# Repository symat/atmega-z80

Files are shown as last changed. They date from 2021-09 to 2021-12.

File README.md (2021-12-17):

ATMega-Z80
==========

We are building here yet another 8bit hobby computer. Because it is fun. And this is what an engineer does, *"MIDWAY upon the journey of our life"*. ;)

Disclaimer: **Use anything in this repo with caution!**

Nothing works yet, we just started to plan the whole thing. The only thing we are sure is that things will change, as we move forward. Plus the fact that we will move forward very slooowly, as this is only a hobby project and everyone is quite busy with other things. 

Table of Contents
-----------------

  * [Goals](#goals)
  * [Hardware design](#hardware-design)
    * [Schema](#schema)
    * [PCB](#pcb)
  * [Using the board](#using-the-board)
  * [Development](#development)
    * [Prerequisites for Linux](#prerequisites-for-linux)
    * [Prerequisites for Windows](#prerequisites-for-windows)
    * [Prerequisites for Mac](#prerequisites-for-mac)
    * [(Optional) Configuring USB HWID](#optional-configuring-usb-hwid)
	* [ATMega Programmer](#atmega-programmer)
	  * [Initializing ATMega clock](#initializing-atmega-clock)
	  * [Deploying the ATMega code](#deploying-the-atmega-code)
	* [Deploying the Z80 'ROM' code](#deploying-the-z80-rom-code)
  * [License](#license)

Goals
=====

**The main goals are:**

 - Using a well-known 8bit CPU.
 - Let's keep the HW design relatively simple. (I'm personally more interested in the 8bit programming part and want to go deeper into the kernel and user code.)
 - We should be able to compile C code to run it on the new computer.
 - We don't need a full-fledged, stand-alone computer. I'm sure everyone has already a few of those on our desks... We don't build this to actually use it for work or gaming.
 - The whole computer should not have more than a handful of ICs. No FPGA or complex MCU with a need for an expensive programmer. Anyone should be able to build it on a breadboard for $40-50 worth of components (incl. programmer). 
 - Don't use logic level (voltage) converters, keep everything e.g. on 5V or on 3.3V.
 - We can have VGA / keyboard / SD Card support later (if someone needs it), but the first thing is to have USB support and connection to a PC, so we can implement a small thin terminal program that can send keyboard and mouse events, display video, play music even.

Hardware design
===============

The basic design is not new or original, it is very much based on other projects available on the internet. I'm especially grateful for [this one, the MBC2 project](https://hackaday.io/project/159973-z80-mbc2-a-4-ics-homebrew-z80-computer) (80% of the HW design comes from this project). 

 - We use a relatively new Z80 CPU, capable to run at 10MHz.
 - A 20MHz ATMega chip (similar to those you can find in Arduino boards) is helping the CPU as ROM emulator, boot loader and clock generator. Also handling all the IO requests from the CPU.
 - An IO wait logic is implemented using an SR latch, forcing the CPU to wait until the ATMega chip processed the IO operations.
 - The ATMgega chip can access both the data bus and the first 4 bits of the address bus. Having access to a part of the address bus makes the boot loading easier and also enables us to use IO and interrupt addresses.
 - For now, we added 512 KB RAM, using 16 KB banks. The CPU will be able to set the bank ID with an IO write operation and then the given 16 KB bank will be visible for the CPU on the third 16KB memory slot of the 64KB address space (between 0x8000 and 0xbfff).
 - We store the bank address in an 8 bit gated D latch IC. This means we can address the banks in 8 bits, so the design works until 4 MB (16KB * 256). But 4MB sounds a bit overkill and also more expensive. It is hard to find a single DIP parallel 8bit SRAM chip over 512 KB. Moving away from DIP makes it harder to assemble the computer on a breadboard, while using many separate 512 KB RAM chips would require a bit more complex banking logic (with lot more footprint and wiring on the breadboard). But in theory we can extend the RAM later easily if needed.
 - We have an USB controller chip, converting the UART port of ATMega to USB.
 - The USB port is used also for powering the whole atmega-z80.
 - We have a user button and LED, both can be used by the programmer to interact directly with the user. (who needs 101 keys and zillion pixels... :p)
 - We plan to add some status indicator LEDs:
	 - Power LED (power come through the USB cable)
	 - Z80 running LED (means the Z80 is active, not in 'halt' state)
	 - USB IO LED (ATMega is communicating through the USB)
	 - CPU IO LED (the CPU is doing IO read or write)
	 - Memory LED (the CPU is reading from / writing to anywhere in the RAM)
	 - Extended memory LED (the CPU is reading from / writing to the banked part of the RAM)
	 - User LED (some program running on the Z80 turned the user LED on)

Schema
------
Please take a look here for the latest version: [schema/atmega-z80.pdf](schema/atmega-z80.pdf)

You can find the editable files in the ['schema' folder](schema/). We use the KICad tool for schema design: https://www.kicad.org/download/

PCB
---

TODO

Using the board
===============

For now, you can only interact with the board using the console application. Later we might add keyboard and display support as well as other periferias. But the console app should be always capable to emulate these, as people might not want to use dedicated periferias for ATMega-Z80.

Prerequisites to use the console:
```
pip3 install pyserial==3.5
```

Using the console:
```
src/console/console.py
```

Development
===========

The source code needs to be deployed into the ATMega chip can be found here: ['src/atmega' folder](src/atmega/)

The source code running on the Z80 can be found here: ['src/z80' folder](src/z80/)

The source code for the console app (running on the PC and connecting to the ATMega on USB): ['src/console' folder](src/z80/)

The console is mainly developed for end users, to interact with the ATMega (until we don't have keyboard and display support, or if the user don't want to buy/attch separate devices to the board). However, during development you can also use the console as a debugger and you can also upload Z80 code using the console. However, to deploy code running on the ATMega, you need to use a programmer (see: [here](#atmega-programmer) )

You can not use the console and the ATMega programmer in the same time. **Make sure you are disconnecting the USB port while you are using the programmer!**

Prerequisites for Linux
-----------------------

TODO

Prerequisites for Windows
-----------------------

TODO

Prerequisites for Mac
---------------------

First, make sure you have xcode command line developer tools installed with:
```
$ xcode-select --install
```

Then install the latest versions of the avr command line tools (avr-libc included in avr-gcc):
```
$ brew tap osx-cross/avr
$ brew install avr-gcc@11 avr-binutils avrdude
```
(you can check the current versions of avr-gcc available through homebrew here: https://github.com/osx-cross/homebrew-avr)

Add the following two lines to your .bash_profile or .zshrc file:
```
export PATH="/usr/local/opt/avr-gcc@11/bin:$PATH"
export AVRGCC_LDFLAGS="-L/usr/local/opt/avr-gcc@11/lib"
```

(Optional) Configuring USB HWID
-------------------------------

You can program the MCP2221A chip, setting the HWID (Vendor ID: 0x1209, Product ID: 0x80A0) of the USB device. We 'registered' an open USB HWID in [pid.codes](https://pid.codes/). This is not mandatory, you can also use the MCP2221A chip with factory default HWID, but in this case the console won't auto-detect the port and you need to select the correct port manually from a list each time you start the console.

**Prerequisites (python):**

```
pip3 install mcp2221==1.0.0
pip3 install hidapi==0.10.1
```

**Prerequisites (C lib):**

The mcp2221 python library is using the hidapi library, which got merged into libusb in 2019. So depending on the age of your OS, you might need to install libhidapi or libusb. 

For me on Mac with up-to-date homebrew, this worked: `brew install hidapi`

According to the project page (https://github.com/trezor/cython-hidapi) for linux this one should work at the moment:
`sudo apt-get install python-dev libusb-1.0-0-dev libudev-dev`

**Setting the HWID for the board**

Use the following command to set the Vendor ID, Product ID and Product Description on the board: `./src/console/program_hwid.py`

**Reseting the HWID**

Use the following command to reset the Vendor ID, Product ID and Product Description on the board to the MPC2221A factory defaults:  `./src/console/program_hwid.py --reset`

ATMega Programmer
-----------------

To update the code running on the ATMega, we are using the open source UABAsp programmer (https://www.fischl.de/usbasp/). It comes with an ISP 10 connector. You need to connect the programmer to the ATMega ports indicated in the schema (RESET and PB3, PB6, PB7). Also you need to connect the 5V and GND from the programmer to the board, basically using the Programmer as a power source while you are programing the board. You can not use the console and the ATMega programmer in the same time. **Make sure you are disconnecting the USB port while you are using the programmer!**

The following photo shows how to connect the ISP 10 connector to your breadboard:

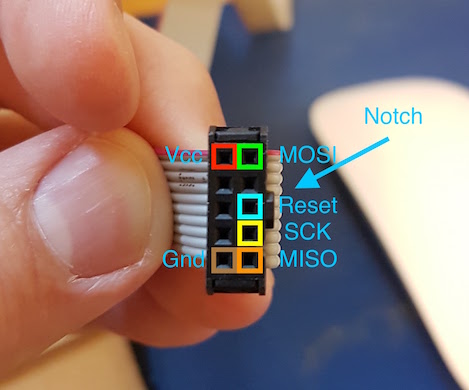
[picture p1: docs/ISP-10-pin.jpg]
USBAsp programmer connector


### Initializing ATMega clock

ATMega shipped with internal 8MHz clock enabled and the clock prescaler set to 8, resulting in 1 MHz clock speed. In the code we assume you wired the 20 MHz crystal to ATMega already. To configure the external crystal oscillator to be used, you need to set the fuses on ATMega once before programming it. (useful online fuse bit calculator: http://eleccelerator.com/fusecalc/fusecalc.php?chip=atmega324pa)

**Make sure you are disconnecting the USB port while you are using the programmer to change the ATMega clock speed!**

You can set the fuses in ATMega to various clock speeds. We support the following speeds:
- 20MHz (the full speed of our external osciallator)
- 8 MHz (internal RC Oscillator)
- 2.5 MHz (dividing the external oscillator speed by 8)
- 1 MHz (internal RC Oscillator, divided by 8; this is the factory default for the ATMega chip)
- 128 KHz (using the internal ATMega slow oscillator - might be tricky, see the slow clock warning)
- 16 KHz (internal slow oscillator, divided by 8 - might be tricky, see the slow clock warning)

When you change the clock speed, you also need to change the MCU_SPEED parameter, to instruct the copmiler to use the proper speed. You need to run `cmake` and `make clean` and `make` to make sure your changes are taking effect. To test your settings, you can use the `make upload_blinky` to upload a program to ATMega which will blink the user led, once in each second. You can see the exact steps below.

```
# if you want to change the clock speed to: 20MHz
make atmega_fuse_init
cmake -DMCU_SPEED=20000000 .

# if you want to change the clock speed to: 8MHz
make atmega_fuse_init_8000khz
cmake -DMCU_SPEED=8000000 .

# if you want to change the clock speed to: 2.5MHz
make atmega_fuse_init_2500khz
cmake -DAVRDUDE_BIT_CLOCK=3 -DMCU_SPEED=2500000 .

# if you want to change the clock speed to: 1MHz (this is the factory default)
make atmega_fuse_factory_reset
cmake -DAVRDUDE_BIT_CLOCK=8 -DMCU_SPEED=1000000 .

# if you want to change the clock speed to: 128KHz (this can be a bit tricky, see the SLOW CLOCK WARNING above)
make atmega_fuse_init_128khz
cmake -DAVRDUDE_BIT_CLOCK=50 -DMCU_SPEED=128000 .

# if you want to change the clock speed to: 16KHz (this can be a bit tricky, see the SLOW CLOCK WARNING above)
make atmega_fuse_init_16khz
cmake -DAVRDUDE_BIT_CLOCK=200 -DMCU_SPEED=16000 .

# you need to rebuild the code with the new clock settings
make clean
make

# this command will make your user LED on the board to flash once in each second
# this way you can make sure the clock is set properly
# (you will have to re-deploy the original ATMega code after this step)
make upload_blinky
```

**!SLOW CLOCK WARNING!** (check this below, before you would try to use the slower clock options)

You might see the following error when you try to program the board, after you changed the clock speed to some slower option:
```
avrdude: error: program enable: target doesn't answer. 1 
avrdude: initialization failed, rc=-1
         Double check connections and try again, or use -F to override
         this check.

avrdude done.  Thank you.
```
The problem can be that the usbasp programmer is trying to talk 'too fast' with the ATMega chip on our board, if you set slow ATMega clocks. Normally you can use the `-B` option for avrdude to instruct the programmer to talk slower. This option can be provided through the AVRDUDE_BIT_CLOCK cmake parameter. I tested the various clock speeds with different AVRDUDE_BIT_CLOCK parameters, so the above examples should work. However, there is a chance that your programmer is different. If you see this error, then you can try to increase the bit clock for your programmer. Also, increasing the bit clock will make the programming slower. So you might want to find the ideal AVRDUDE_BIT_CLOCK for your programmer.

An other 'slow clock' problem you can face with usbasp programmer is that avrdude actually is unable to set the bit clock:
```
avrdude: warning: cannot set sck period. please check for usbasp firmware update.
```
Based on some googling, this happens when you have a very old usbasp programmer or if your programmer has some non-official usbasp frameware. In this case you either need to upgrade the programmer's firmware or you need to connect the 'slow clock' jumper on your programmer. This is JP1 on the original schematic of usbasp (https://www.fischl.de/usbasp/), while in case of my programmer, this was actually marked as JP3 (so be careful). If you choose the other option, the latest frameware can be downloaded from the usbasp site. However you will need to have a second programmer to be able to refresh the framework of your original programmer. (but I had to do this, as in my case even the 'slow clock' jumper was not enough after I set my ATMgit statusega to 16KHz)

Anyway, if you don't want to spend time on these 'slow clock' problems then you can simply skip using clock rates slower than 1 MHz.

### Deploying the ATMega code

Below it is shown how can you build the atmega code and flash it to ATMega. Note, the ATMega flash will not contain the Z80 'ROM code'. The Z80 code can be copied to ATMega by using the console app. **Make sure you are disconnecting the USB port while you are using the programmer!**
```
make clean
make
make upload_z80_prog_loader
```

Deploying the Z80 ROM code
--------------------------

The memory will be initialized on startup by the ATMega chip, copying the Z80 'ROM' into the memory from the ATMega flash. To update Z80 ROM, you don't need an AVR Programmer, you can use the console to uppload the new ROM file to ATMega.

```
TODO
```

License
=======
This is an open project. The software is licensed under BSD-3, while the hardware is licensed under CERN-OHL-P. Both licenses are permissive. Feel free to use anything here, just don't point fingers / blame us ;)

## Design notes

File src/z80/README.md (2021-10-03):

Source code running on the Z80

- **blinky.asm**: Blinks the user LED at 1Hz
- **bootloader.asm**: Copies code into memory via IO requests then executes it
- **hello.asm**: Prints "Hello World!" to the console

Assembly sources are using [Pasmo](https://pasmo.speccy.org/)'s syntax

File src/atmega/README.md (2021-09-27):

Source code running on the ATMega

- **blinky.c**: Blinks the user LED
- **z80_prog_loader.c**: Listens for code upload requests on the serial port and uploads code into memory for execution by the Z80

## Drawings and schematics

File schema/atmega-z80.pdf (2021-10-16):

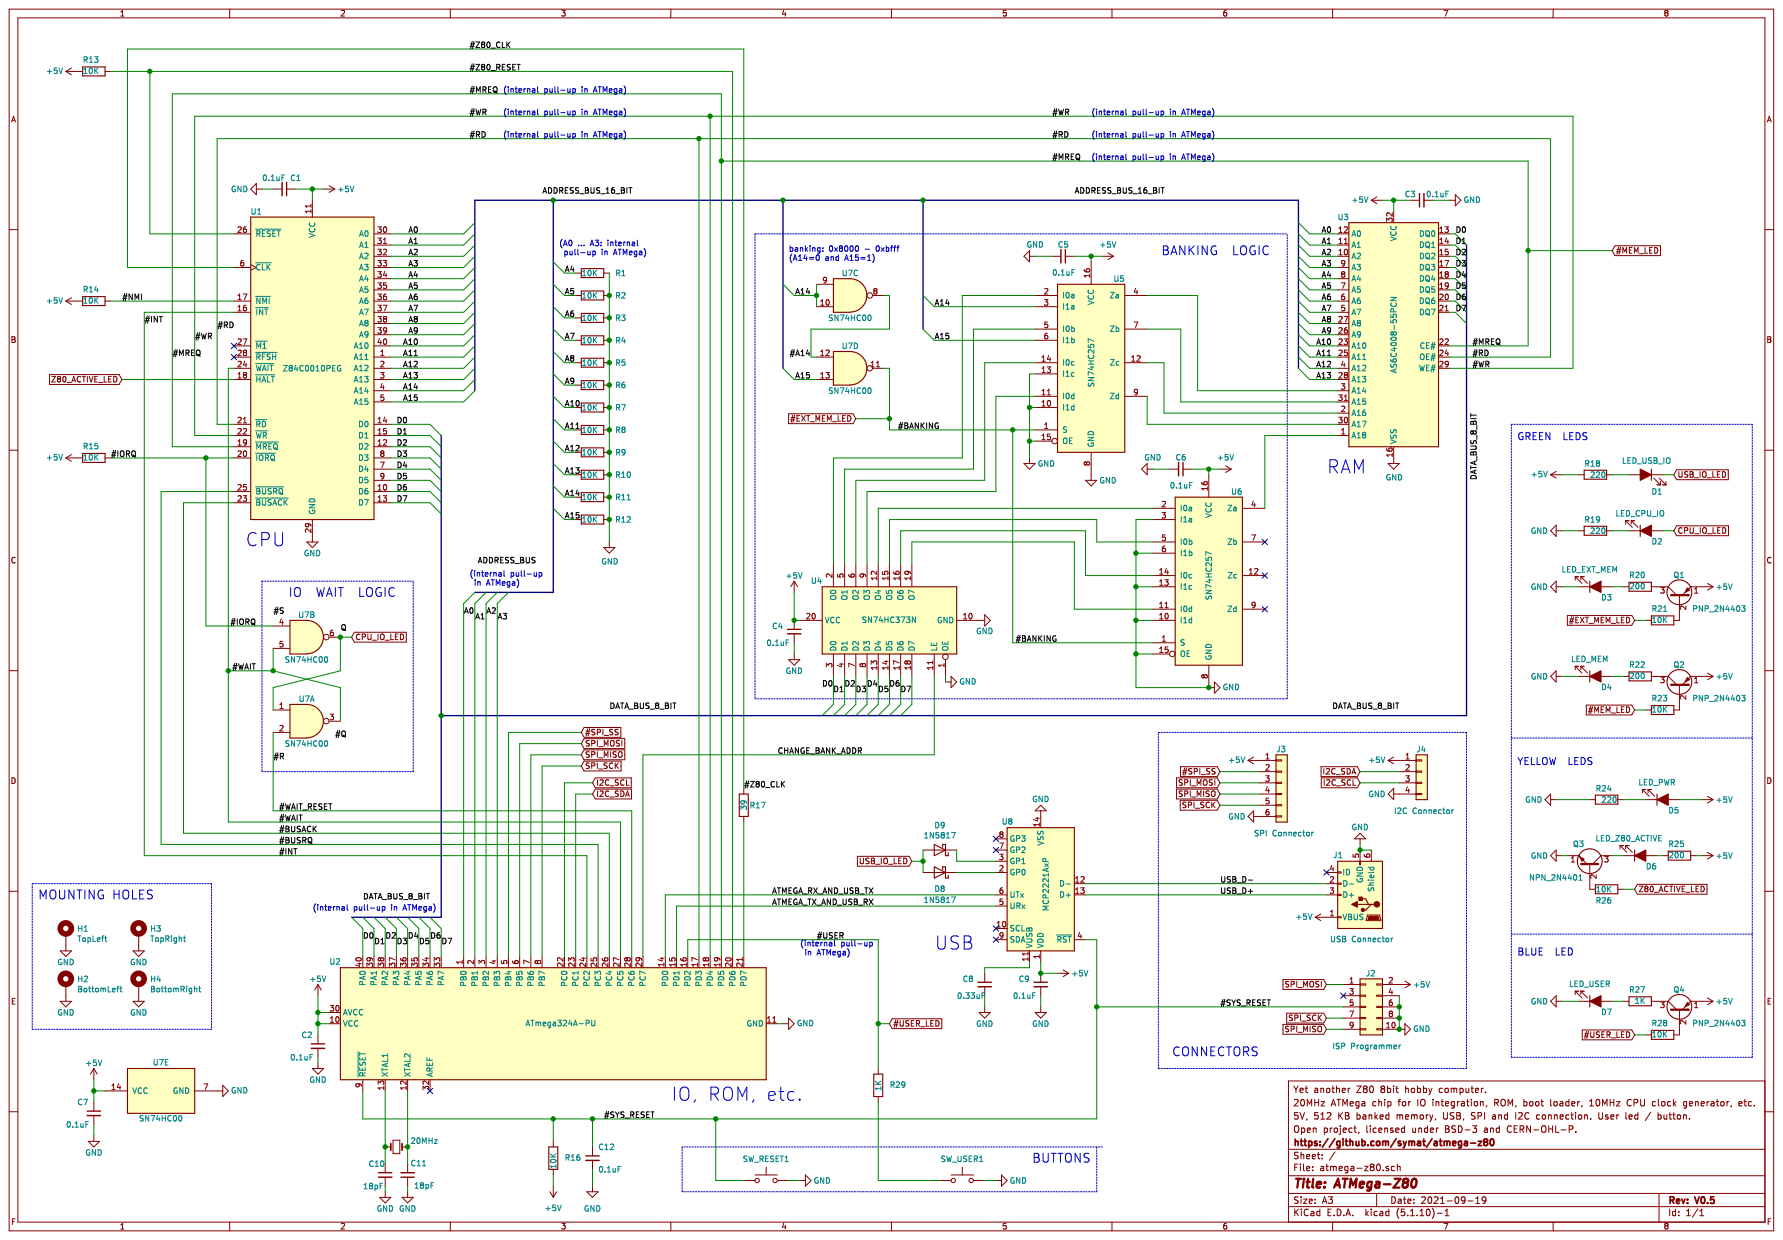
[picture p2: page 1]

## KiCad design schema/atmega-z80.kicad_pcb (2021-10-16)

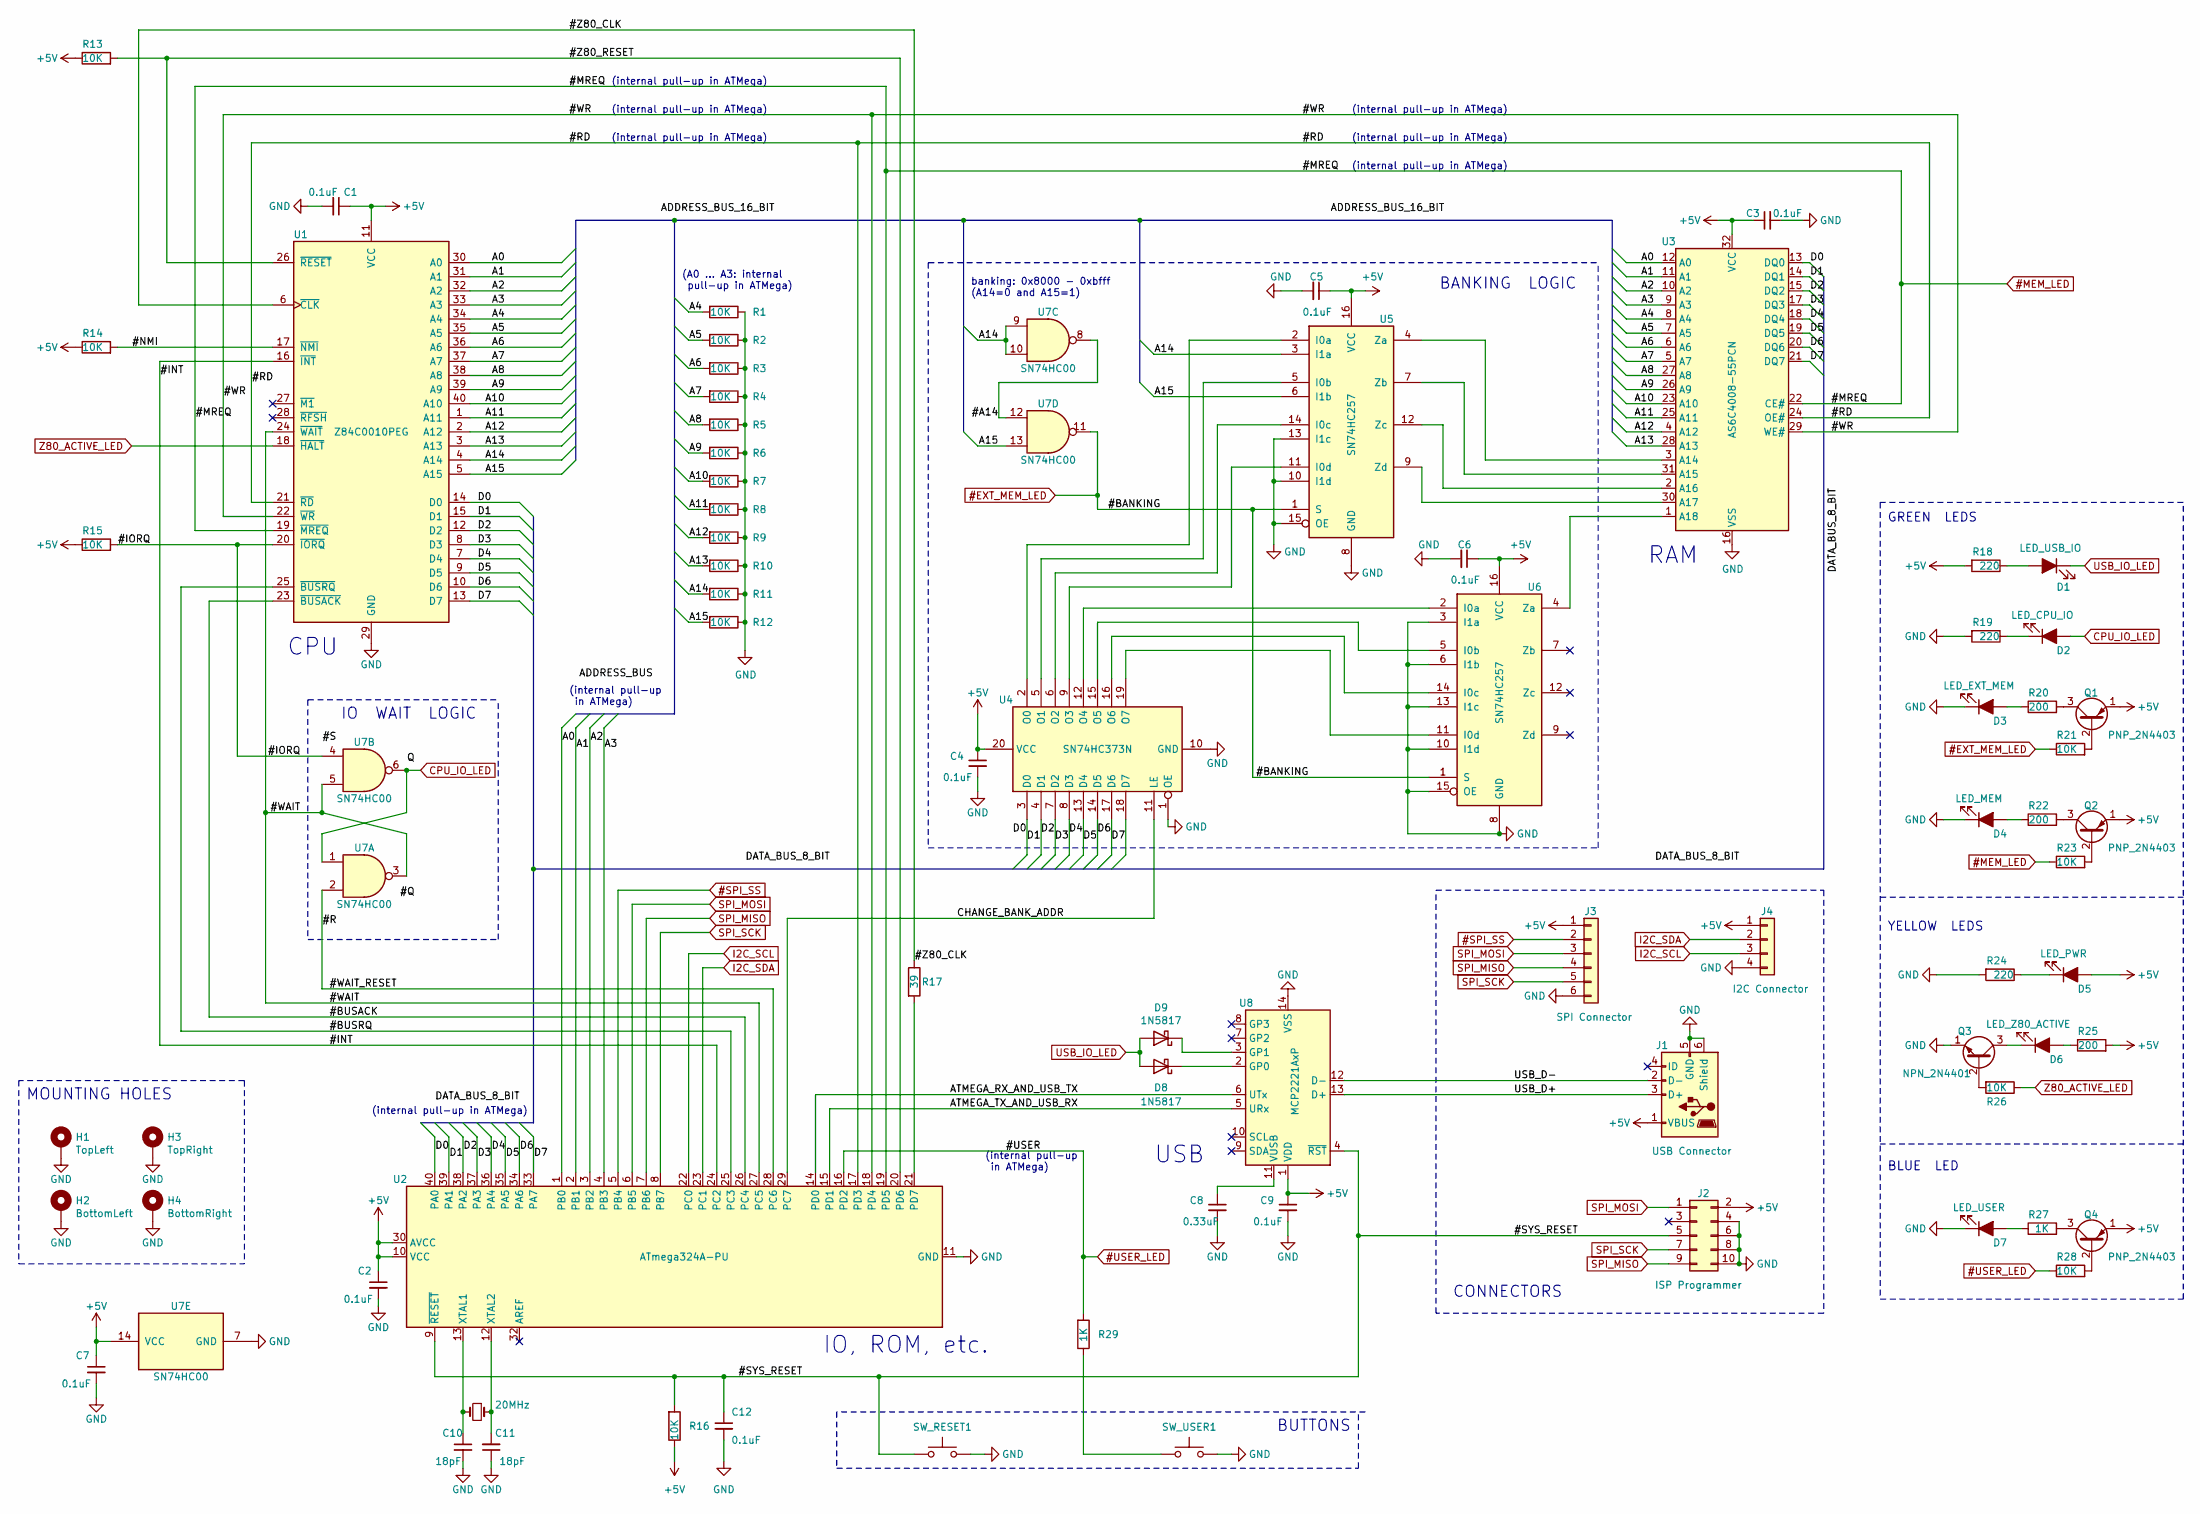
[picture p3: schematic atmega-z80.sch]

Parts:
C1, C2, C3, C4, C5, C6, C7, C9, C12: 0.1uF; C_1206_3216Metric_Pad1.33x1.80mm_HandSolder
C8: 0.33uF; C_1206_3216Metric_Pad1.33x1.80mm_HandSolder
C10, C11: 18pF; C_1206_3216Metric_Pad1.33x1.80mm_HandSolder
D1: LED_USB_IO; LED_D5.0mm
D2: LED_CPU_IO; LED_D5.0mm
D3: LED_EXT_MEM; LED_D5.0mm
D4: LED_MEM; LED_D5.0mm
D5: LED_PWR; LED_D5.0mm
D6: LED_Z80_ACTIVE; LED_D5.0mm
D7: LED_USER; LED_D5.0mm
D8, D9: 1N5817; D_DO-41_SOD81_P10.16mm_Horizontal
H1: TopLeft; MountingHole_2.2mm_M2_DIN965_Pad
H2: BottomLeft; MountingHole_2.2mm_M2_DIN965_Pad
H3: TopRight; MountingHole_2.2mm_M2_DIN965_Pad
H4: BottomRight; MountingHole_2.2mm_M2_DIN965_Pad
J1: USB Connector; USB_Mini-B_Molex-54819-0519
J2: ISP Programmer; PinHeader_2x05_P2.54mm_Vertical
J3: SPI Connector; PinHeader_1x06_P2.54mm_Vertical
J4: I2C Connector; PinHeader_1x04_P2.54mm_Vertical
Q1, Q2, Q4: PNP_2N4403; TO-92_Inline
Q3: NPN_2N4401; TO-92_Inline_Wide
R1, R2, R3, R4, R5, R6, R7, R8, R9, R10, R11, R12, R13, R14, R15, R16, R21, R23, R26, R28: 10K; R_1206_3216Metric_Pad1.30x1.75mm_HandSolder
R17: 39; R_1206_3216Metric_Pad1.30x1.75mm_HandSolder
R18, R19, R24: 220; R_1206_3216Metric_Pad1.30x1.75mm_HandSolder
R20, R22, R25: 200; R_1206_3216Metric_Pad1.30x1.75mm_HandSolder
R27, R29: 1K; R_1206_3216Metric_Pad1.30x1.75mm_HandSolder
SW_RESET1: RESET; SW_PUSH_6mm_H5mm
SW_USER1: USER; SW_PUSH_6mm_H5mm
U1: Z84C0010PEG; DIP-40_W15.24mm_Socket
U2: ATmega324A-PU; DIP-40_W15.24mm_Socket
U3: AS6C4008-55PCN; DIP-32_W15.24mm_Socket
U4: SN74HC373N; DIP-20_W7.62mm_Socket
U5, U6: SN74HC257; DIP-16_W7.62mm_Socket
U7: SN74HC00; DIP-14_W7.62mm_Socket
U8: MCP2221AxP; DIP-14_W7.62mm_Socket
Y1: 20MHz; Crystal_HC49-U_Vertical

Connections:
#EXT_MEM_LED: R21.1, U5.1 (S), U6.1 (S), U7.11
#MEM_LED: R23.1, U1.19 (~MREQ~), U2.19 (PD5), U3.22 (CE#)
#SPI_SS: J3.2, U2.5 (PB4)
#USER_LED: R28.1, R29.2, U2.16 (PD2)
+5V: C1.1, C2.1, C3.1, C4.1, C5.1, C6.1, C7.1, C9.1, D5.2 (A), J1.1 (VBUS), J2.2, J3.1, J4.1, Q1.1 (E), Q2.1 (E), Q4.1 (E), R13.1, R14.1, R15.1, R16.1, R18.2, R25.2, U1.11 (VCC), U2.10 (VCC), U2.30 (AVCC), U3.32 (VCC), U4.20 (VCC), U5.16 (VCC), U6.16 (VCC), U7.14 (VCC), U8.1 (VDD)
/#A14: U7.8, U7.12
/#BUSACK: U1.23 (~BUSACK~), U2.26 (PC4)
/#BUSRQ: U1.25 (~BUSRQ~), U2.25 (PC3)
/#INT: U1.16 (~INT~), U2.24 (PC2)
/#IORQ: R15.2, U1.20 (~IORQ~), U7.4
/#NMI: R14.2, U1.17 (~NMI~)
/#R: U2.28 (PC6), U7.2
/#RD: U1.21 (~RD~), U2.17 (PD3), U3.24 (OE#)
/#SYS_RESET: C12.1, J2.5, R16.2, SW_RESET1.2, U2.9 (~RESET), U8.4 (~RST)
/#WAIT: U1.24 (~WAIT~), U2.27 (PC5), U7.3, U7.5
/#WR: U1.22 (~WR~), U2.18 (PD4), U3.29 (WE#)
/#Z80_CLK: R17.1, U1.6 (~CLK~)
/#Z80_RESET: R13.2, U1.26 (~RESET~), U2.20 (PD6)
/A0: U1.30 (A0), U2.1 (PB0), U3.12 (A0)
/A1: U1.31 (A1), U2.2 (PB1), U3.11 (A1)
/A2: U1.32 (A2), U2.3 (PB2), U3.10 (A2)
/A3: U1.33 (A3), U2.4 (PB3), U3.9 (A3)
/A4: R1.2, U1.34 (A4), U3.8 (A4)
/A5: R2.2, U1.35 (A5), U3.7 (A5)
/A6: R3.2, U1.36 (A6), U3.6 (A6)
/A7: R4.2, U1.37 (A7), U3.5 (A7)
/A8: R5.2, U1.38 (A8), U3.27 (A8)
/A9: R6.2, U1.39 (A9), U3.26 (A9)
/A10: R7.2, U1.40 (A10), U3.23 (A10)
/A11: R8.2, U1.1 (A11), U3.25 (A11)
/A12: R9.2, U1.2 (A12), U3.4 (A12)
/A13: R10.2, U1.3 (A13), U3.28 (A13)
/A14: R11.2, U1.4 (A14), U5.3 (I1a), U7.9, U7.10
/A15: R12.2, U1.5 (A15), U5.6 (I1b), U7.13
/ATMEGA_RX_AND_USB_TX: U2.14 (PD0), U8.6 (UTx)
/ATMEGA_TX_AND_USB_RX: U2.15 (PD1), U8.5 (URx)
/CHANGE_BANK_ADDR: U2.29 (PC7), U4.11 (LE)
/D0: U1.14 (D0), U2.40 (PA0), U3.13 (DQ0), U4.3 (D0)
/D1: U1.15 (D1), U2.39 (PA1), U3.14 (DQ1), U4.4 (D1)
/D2: U1.12 (D2), U2.38 (PA2), U3.15 (DQ2), U4.7 (D2)
/D3: U1.8 (D3), U2.37 (PA3), U3.17 (DQ3), U4.8 (D3)
/D4: U1.7 (D4), U2.36 (PA4), U3.18 (DQ4), U4.13 (D4)
/D5: U1.9 (D5), U2.35 (PA5), U3.19 (DQ5), U4.14 (D5)
/D6: U1.10 (D6), U2.34 (PA6), U3.20 (DQ6), U4.17 (D6)
/D7: U1.13 (D7), U2.33 (PA7), U3.21 (DQ7), U4.18 (D7)
/USB_D+: J1.3 (D+), U8.13 (D+)
/USB_D-: J1.2 (D-), U8.12 (D-)
CPU_IO_LED: D2.2 (A), U7.1, U7.6
GND: C1.2, C2.2, C3.2, C4.2, C5.2, C6.2, C7.2, C8.2, C9.2, C10.2, C11.1, C12.2, D3.1 (K), D4.1 (K), D7.1 (K), H1.1, H2.1, H3.1, H4.1, J1.5 (GND), J1.6 (Shield), J2.4, J2.6, J2.8, J2.10, J3.6, J4.4, Q3.1 (E), R1.1, R2.1, R3.1, R4.1, R5.1, R6.1, R7.1, R8.1, R9.1, R10.1, R11.1, R12.1, R19.2, R24.2, SW_RESET1.1, SW_USER1.2, U1.29 (GND), U2.11 (GND), U2.31 (GND), U3.16 (VSS), U4.1 (OE), U4.10 (GND), U5.8 (GND), U5.10 (I1d), U5.13 (I1c), U5.15 (OE), U6.3 (I1a), U6.6 (I1b), U6.8 (GND), U6.10 (I1d), U6.13 (I1c), U6.15 (OE), U7.7 (GND), U8.14 (VSS)
I2C_SCL: J4.3, U2.22 (PC0)
I2C_SDA: J4.2, U2.23 (PC1)
unnamed: C8.1, U8.11 (VUSB)
unnamed: C10.1, U2.13 (XTAL1), Y1.2
unnamed: C11.2, U2.12 (XTAL2), Y1.1
unnamed: D1.2 (A), R18.1
unnamed: D2.1 (K), R19.1
unnamed: D3.2 (A), R20.1
unnamed: D4.2 (A), R22.1
unnamed: D5.1 (K), R24.1
unnamed: D6.1 (K), Q3.3 (C)
unnamed: D6.2 (A), R25.1
unnamed: D7.2 (A), R27.1
unnamed: D8.1 (K), U8.2 (GP0)
unnamed: D9.1 (K), U8.3 (GP1)
unnamed: Q1.2 (B), R21.2
unnamed: Q1.3 (C), R20.2
unnamed: Q2.2 (B), R23.2
unnamed: Q2.3 (C), R22.2
unnamed: Q3.2 (B), R26.2
unnamed: Q4.2 (B), R28.2
unnamed: Q4.3 (C), R27.2
unnamed: R17.2, U2.21 (PD7)
unnamed: R29.1, SW_USER1.1
unnamed: U3.1 (A18), U6.4 (Za)
unnamed: U3.2 (A16), U5.12 (Zc)
unnamed: U3.3 (A14), U5.4 (Za)
unnamed: U3.30 (A17), U5.9 (Zd)
unnamed: U3.31 (A15), U5.7 (Zb)
unnamed: U4.2 (O0), U5.2 (I0a)
unnamed: U4.5 (O1), U5.5 (I0b)
unnamed: U4.6 (O2), U5.14 (I0c)
unnamed: U4.9 (O3), U5.11 (I0d)
unnamed: U4.12 (O4), U6.2 (I0a)
unnamed: U4.15 (O5), U6.5 (I0b)
unnamed: U4.16 (O6), U6.14 (I0c)
unnamed: U4.19 (O7), U6.11 (I0d)
SPI_MISO: J2.9, J3.4, U2.7 (PB6)
SPI_MOSI: J2.1, J3.3, U2.6 (PB5)
SPI_SCK: J2.7, J3.5, U2.8 (PB7)
USB_IO_LED: D1.1 (K), D8.2 (A), D9.2 (A)
Z80_ACTIVE_LED: R26.1, U1.18 (~HALT~)

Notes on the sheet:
BUTTONS
CONNECTORS
IO WAIT LOGIC
CPU
IO, ROM, etc.
RAM
BANKING LOGIC
YELLOW LEDS
GREEN LEDS
BLUE LED
(internal pull-up in ATMega)
(A0 … A3: internal pull-up in ATMega)
banking: 0x8000 - 0xbfff (A14=0 and A15=1)
USB
(internal pull-up in ATMega)
MOUNTING HOLES

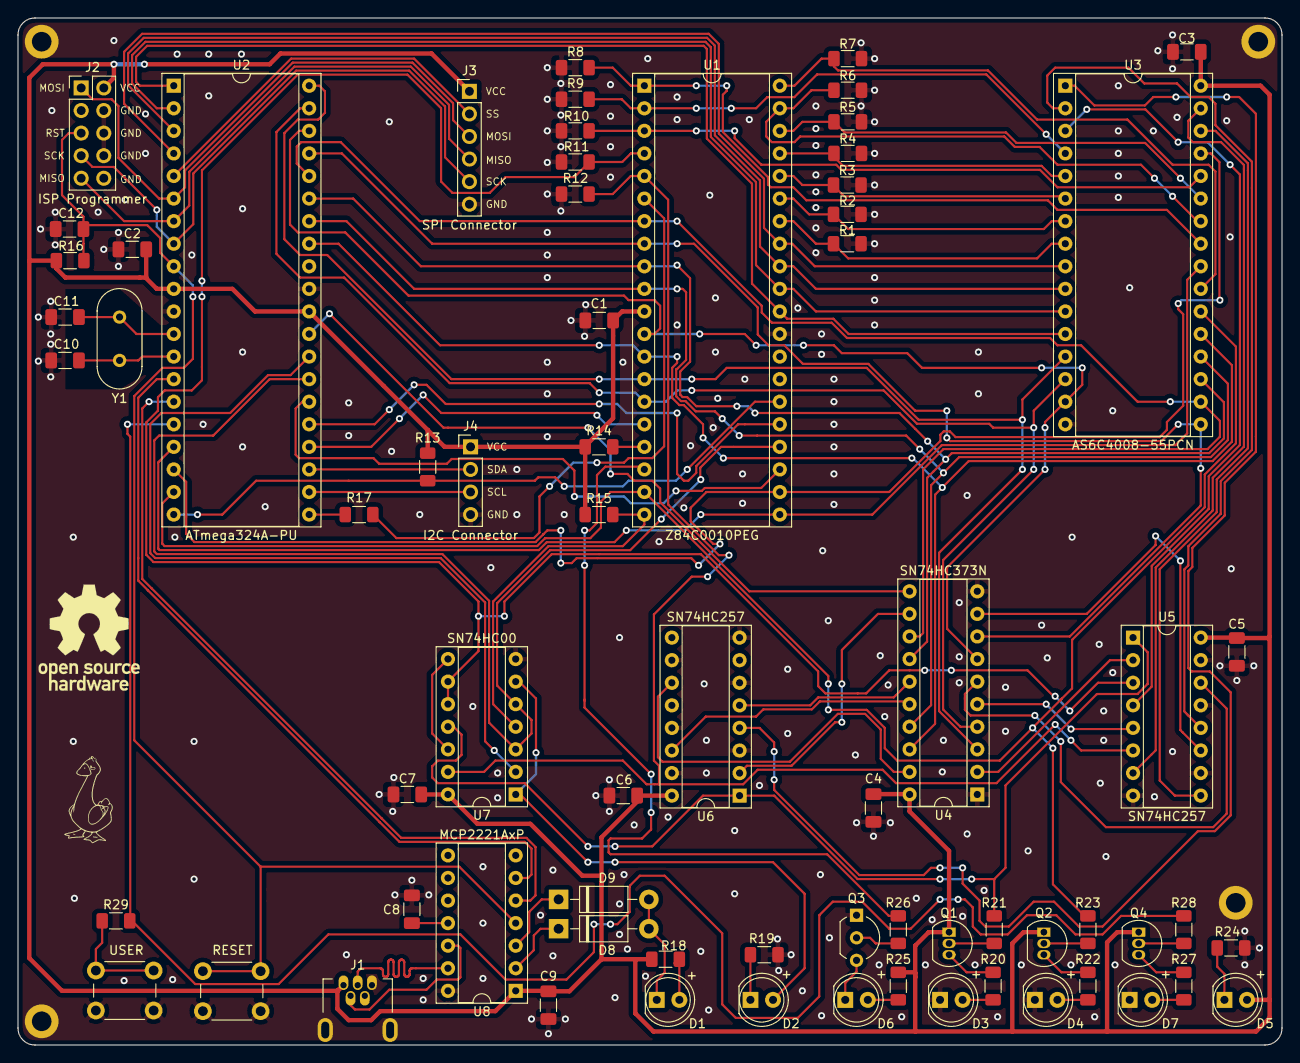
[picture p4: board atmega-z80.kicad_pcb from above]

Board: 2 copper layers, 142.2 x 115.6 mm, 73 parts (0 on the bottom side), 91 nets.

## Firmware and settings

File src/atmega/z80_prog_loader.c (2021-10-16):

#include <avr/io.h>
#include <avr/interrupt.h>
#include <stdint.h>

#define USART_BAUD_RATE 9600

#define PORT_DATA_BUS PORTA
#define DDR_DATA_BUS DDRA
#define PIN_DATA_BUS PINA

#define PORT_ADDRESS_BUS PORTB
#define DDR_ADDRESS_BUS DDRB
#define PIN_ADDRESS_BUS PINB

#define PORT_SIG1 PORTC
#define DDR_SIG1 DDRC
#define PIN_SIG1 PINC

#define PORT_SIG2 PORTD
#define DDR_SIG2 DDRD
#define PIN_SIG2 PIND

#define BUSRQ_SIG1 PC3
#define BUSACK_SIG1 PC4
#define WAIT_SIG1 PC5
#define WAIT_RESET_SIG1 PC6
#define CHANGE_BANK_ADDR_SIG1 PC7

#define USER_LED_SWITCH_SIG2 PD2
#define RD_SIG2 PD3
#define WR_SIG2 PD4
#define MREQ_SIG2 PD5
#define RESET_SIG2 PD6

#define MEM_OE_SIG2 RD_SIG2
#define MEM_WE_SIG2 WR_SIG2
#define MEM_CE_SIG2 MREQ_SIG2

#define IO_PORT_CONSOLE 0
#define IO_PORT_USER_LED_SWITCH 1
#define IO_PORT_MEMORY_BANK 2

#define IO_USER_DISABLE_LED 0
#define IO_USER_ENABLE_LED 1
#define IO_USER_SELECT_LED_MODE 2
#define IO_USER_SELECT_SWITCH_MODE 3

#define CMD_LOAD_Z80_BINARY_FROM_USART 1

#define ERR_OK 0
#define ERR_TIMEOUT 1
#define ERR_INVALID_SIZE 2
#define ERR_CHECKSUM_FAILED 3

#define INLINE static __attribute__((always_inline)) inline

static const uint8_t bootloader_code[] = {
    0xAF, 0x4F, 0xED, 0x50, 0x21, 0x00, 0x01, 0x47,
    0xED, 0xB2, 0x15, 0x20, 0xFB, 0xC3, 0x00, 0x01,
};

// The currently selected memory bank
uint8_t memory_bank;

INLINE void acquire_data_bus() {    
    DDR_DATA_BUS = 0b11111111;
}

INLINE void release_data_bus() {
    PORT_DATA_BUS = 0b11111111;
    DDR_DATA_BUS = 0b00000000;
}

INLINE void acquire_address_bus() {
    DDR_ADDRESS_BUS |= 0b00001111;
}

INLINE void release_address_bus() {
    PORT_ADDRESS_BUS |= 0b00001111;
    DDR_ADDRESS_BUS &= 0b11110000;
}

static void setup_pins() {
    // Pull #RESET line down to prevent Z80
    // to drive any lines during setup
    DDR_SIG2 |= (1 << RESET_SIG2);
    PORT_SIG2 &= ~(1 << RESET_SIG2);

    // Data bus D0 - D7
    // Enable pull-ups
    DDR_DATA_BUS = 0b00000000;
    PORT_DATA_BUS = 0b11111111;

    // Address bus A0 - A3
    // Enable pull-ups
    DDR_ADDRESS_BUS &= 0b11110000;
    PORT_ADDRESS_BUS |= 0b00001111;

    /*
     *  SIG1 group
     *
     *  PC0 - I2C SCL (input, pull-up)
     *  PC1 - I2C SDA (input, pull-up)
     *  PC2 - #INT line (output, high)
     *  PC3 - #BUSRQ line (output, high)
     *  PC4 - #BUSACK line (input, no pull-up)
     *  PC5 - #WAIT line (input, no pull-up)
     *  PC6 - #WAIT_RESET line (output, high)
     *  PC7 - CHANGE_BANK_ADDR line (output, low)
     */
    DDR_SIG1 = 0b11001100;
    PORT_SIG1 = 0b01001111;

    /*
     *  SIG2 group
     *
     *  PD0 - USART RxD (input, pull-up)
     *  PD1 - USART TxD (output, high)
     *  PD2 - User switch (input, pull-up)
     *  PD3 - #RD (input, pull-up)
     *  PD4 - #WR (input, pull-up)
     *  PD5 - #MREQ (input, pull-up)
     *  PD6 - #RESET (output, low)
     *  PD7 - #CLK (output, high)
     */
    DDR_SIG2 = 0b11000010;
    PORT_SIG2 = 0b10111111;

    // Interrupt request on falling edge of INT2
    EICRA = (1 << ISC21)
          | (0 << ISC20);

    // Enable pin change interrupt 2, which enables PCINT16-23
    // #WAIT line is connected to PC5 which corresponds to PCINT21
    PCICR |= (1 << PCIE2);

    // Enable pin change interrupt on PCINT21 (PC5 aka #WAIT line)
    PCMSK2 |= (1 << PCINT21);
}

 INLINE void signal_io_complete() {
    // Pulse #WAIT_RESET line
    PIN_SIG1 |= (1 << WAIT_RESET_SIG1);
    PIN_SIG1 |= (1 << WAIT_RESET_SIG1);
}

INLINE void wait_z80_read_complete() {
    while (!(PIN_SIG2 & (1 << RD_SIG2))) {}
}

static void console_io_handler(uint8_t input_request) {
    if (input_request) {
        // TODO

    } else {
        // Send one character via USART
        UDR0 = PIN_DATA_BUS;
    }
}

static void user_io_handler(uint8_t input_request) {
    if (input_request) {
        acquire_data_bus();
        // Put led / switch status on data bus
        PORT_DATA_BUS = (PIN_SIG2 & (1 << USER_LED_SWITCH_SIG2)) == 0;

    } else {
        // Read IO data from data bus
        const uint8_t cmd = PIN_DATA_BUS;
        switch (cmd) {
            case IO_USER_DISABLE_LED:
                // Check if LED mode is selected
                if (DDR_SIG2 & (1 << USER_LED_SWITCH_SIG2)) {
                    PORT_SIG2 |= (1 << USER_LED_SWITCH_SIG2);
                }
                break;

            case IO_USER_ENABLE_LED:
                // Check if LED mode is selected
                if (DDR_SIG2 & (1 << USER_LED_SWITCH_SIG2)) {
                    PORT_SIG2 &= ~(1 << USER_LED_SWITCH_SIG2);    
                }
                break;

            case IO_USER_SELECT_LED_MODE:
                // Select output mode on USER_LED_SWITCH line
                DDR_SIG2 |= (1 << USER_LED_SWITCH_SIG2);
                // Disable LED
                PORT_SIG2 |= (1 << USER_LED_SWITCH_SIG2);
                break;

            case IO_USER_SELECT_SWITCH_MODE:
                // Select input mode on USER_LED_SWITCH line
                DDR_SIG2 &= ~(1 << USER_LED_SWITCH_SIG2);
                // Activate pull-up
                PORT_SIG2 |= (1 << USER_LED_SWITCH_SIG2);
                break;
        }
    }
}

static void memory_bank_io_handler(uint8_t input_request) {
    if (input_request) {
        acquire_data_bus();
        PORT_DATA_BUS = memory_bank;
        
    } else {
        // New bank index is on data bus
        memory_bank = PIN_DATA_BUS;

        // Pulse CHANGE_BANK_ADDR
        PIN_SIG1 |= (1 << CHANGE_BANK_ADDR_SIG1);
        PIN_SIG1 |= (1 << CHANGE_BANK_ADDR_SIG1);
    }
}

// IO request handler
// Will be called on the falling edge of #WAIT
ISR(PCINT2_vect) {
    // Read the IO port address from address bus
    const uint8_t io_port = PIN_ADDRESS_BUS & 0b00001111;
    // Determine direction of request
    const uint8_t input_request = (PIN_SIG2 & (1 << RD_SIG2)) == 0;

    switch (io_port) {
        case IO_PORT_CONSOLE:
            console_io_handler(input_request);
            break;

        case IO_PORT_USER_LED_SWITCH:
            user_io_handler(input_request);
            break;

        case IO_PORT_MEMORY_BANK:
            memory_bank_io_handler(input_request);
            break;
    }

    // Signal bus request
    PORT_SIG1 &= ~(1 << BUSRQ_SIG1);
    signal_io_complete();
    // Wait for Z80 to release the bus
    while (PIN_SIG1 & (1 << BUSACK_SIG1)) {}

    if (input_request) {
        release_data_bus();
    }

    // Signal bus release
    PORT_SIG1 |= (1 << BUSRQ_SIG1);
}

static void setup_usart() {
    // Setup baud rate
    //
    // See atmega datasheet page 178
    const uint16_t ubrr = (F_CPU / (16U * USART_BAUD_RATE)) - 1;
    UBRR0H = (ubrr >> 8) & 0x0F;
    UBRR0L = ubrr & 0xFF;

    UCSR0B = (1 << RXEN0)    // enable receiver
           | (1 << TXEN0)    // enable transmitter
           | (0 << UCSZ02);  // 8-bit char size
    UCSR0C = (0 << UMSEL01)  // async. mode
           | (0 << UMSEL00)
           | (0 << UPM01)    // disable parity check
           | (0 << UPM00)
           | (0 << USBS0)    // 1 stop bit
           | (1 << UCSZ01)   // 8-bit char size cont.
           | (1 << UCSZ00)
           | (0 << UCPOL0);  // clock polarity
}

INLINE void bus_request() {
    PORT_SIG1 &= ~(1 << BUSRQ_SIG1);
    while (PIN_SIG1 & (1 << BUSACK_SIG1)) {}
}

INLINE void bus_release() {
    PORT_SIG1 |= (1 << BUSRQ_SIG1);
}

static void set_memory_bank(uint8_t bank) {
    // Save memory bank index
    memory_bank = bank;

    acquire_data_bus();
    
    // Put bank address on data bus
    PORT_DATA_BUS = bank;

    // Pulse CHANGE_BANK_ADDR
    // One clock cycle (~50ns) should be long enough.
    //
    // See SN74HC373 datasheet page 4
    PIN_SIG1 |= (1 << CHANGE_BANK_ADDR_SIG1);
    PIN_SIG1 |= (1 << CHANGE_BANK_ADDR_SIG1);

    release_data_bus();
}

static void switch_memory_bank(uint8_t bank) {
    bus_request();
    set_memory_bank(bank);
    bus_release();
}

static void upload_bootloader() {
    const uint8_t bootloader_size = sizeof(bootloader_code);

    // See AS6C4008 datasheet page 3

    // Acquire #OE, #WE and #CE lines of memory IC
    DDR_SIG2 |= (1 << MEM_OE_SIG2)
             |  (1 << MEM_WE_SIG2)
             |  (1 << MEM_CE_SIG2);

    PORT_SIG2 |= (1 << MEM_OE_SIG2)  // Set #OE high to ensure that the memory IC won't drive the data bus
              |  (1 << MEM_WE_SIG2)  // Set #WE high to ensure that no data will be written to memory by accedent
              |  (1 << MEM_CE_SIG2); // Set #CE to high to disable memory IC

    acquire_data_bus();
    acquire_address_bus();

    // Enable memory IC
    PORT_SIG2 &= ~(1 << MEM_CE_SIG2);

    for (uint8_t i = 0; i < bootloader_size; i++) {
        // Put next byte on the data bus
        PORT_DATA_BUS = bootloader_code[i];
        // Put address on the address bus
        PORT_ADDRESS_BUS = (i & 0b00001111);

        // Pulse #WE
        // The width of a write pulse must be at least 45ns long.
        // With a clock speed of 20Mhz one cycle is 50ns long so no
        // additional delay is required before setting the #WE line
        // high again.
        //
        // See AS6C4008 datasheet pages 4 and 6
        PIN_SIG2 |= (1 << MEM_WE_SIG2);
        PIN_SIG2 |= (1 << MEM_WE_SIG2);
    }

    release_address_bus();
    release_data_bus();

    // Set #OE, #WE, #CE lines to high (will enable pull-up on release)
    PORT_SIG2 |= (1 << MEM_OE_SIG2)
              |  (1 << MEM_WE_SIG2)
              |  (1 << MEM_CE_SIG2);

    // Release #OE, #WE, #CE lines
    DDR_SIG2 &= ~(
          (1 << MEM_OE_SIG2)
        | (1 << MEM_WE_SIG2)
        | (1 << MEM_CE_SIG2)
    );
}

INLINE void enable_z80_cpu() {
    PORT_SIG2 |= (1 << RESET_SIG2);
}

INLINE void disable_z80_cpu() {
    PORT_SIG2 &= ~(1 << RESET_SIG2);
}

static void setup_z80_clock() {
    // Set output compare to zero. This will give us
    // a frequency of f_clk / [2N * (1 + OCR2A)] = f_clk / 2, where
    // N = prescaling factor (=1)
    //
    // See atmega datasheet page 152
    OCR2A = 0;

    TCCR2A = (0 << COM2A1)   // Toggle OC2A (PD7) on compare match
           | (1 << COM2A0)
           | (0 << COM2B1)   // Disconnect OC2B (PD6)
           | (0 << COM2B0)
           | (1 << WGM21)    // CTC mode (bits 1-0)
           | (0 << WGM20);

    TCCR2B = (0 << FOC2A)    // Disable force output compare A
           | (0 << FOC2B)    // Disable force output compare B
           | (0 << WGM22)    // CTC mode (bit 2)
           | (0 << CS22)     // No clock source (timer is stopped)
           | (0 << CS21)
           | (0 << CS20);
}

static void start_z80_clock() {
    TCCR2B |= (0 << CS22)     // Use system clock without prescaler (/1)
           |  (0 << CS21)
           |  (1 << CS20);
}

static void stop_z80_clock() {
    TCCR2B &= ~((1 << CS22)   // No clock source (timer is stopped)
           |    (1 << CS21)
           |    (1 << CS20));
}

static void setup_usart_timeout_timer() {
    // Use 16-bit timer/counter1
    TCCR1A = (0 << COM1A1)    // Disconnect OC1A (PD5)
           | (0 << COM1A0)
           | (0 << COM1B1)    // Disconnect OC1B (PD4)
           | (0 << COM1B0)
           | (0 << WGM11)     // CTC mode (bits 1-0)
           | (0 << WGM10);

    TCCR1B = (0 << ICNC1)     // Disable input capture noise canceller
           | (0 << ICES1)     // Input capture select falling edge (ignored)
           | (0 << WGM13)     // CTC mode (bits 2-3)
           | (1 << WGM12)
           | (0 << CS12)      // No clock source (timer is stopped)
           | (0 << CS11)
           | (0 << CS10);
}

static void start_usart_timeout_timer(uint16_t bytes_expected) {
    const uint8_t cycles_per_byte = F_CPU * 10UL / USART_BAUD_RATE / 1024UL + 1;
    const uint16_t max_bytes = 65535UL / cycles_per_byte;

    // Zero counter
    TCNT1L = 0;
    TCNT1H = 0;

    // Set timeout counter
    if (bytes_expected <= max_bytes) {
        // Set counter according to bytes_expected
        const uint16_t cnt = cycles_per_byte * bytes_expected;
        OCR1AL = cnt & 0xFF;
        OCR1AH = cnt >> 8;

    } else {
        // Set maximum counter value possible
        OCR1AL = 0xFF;
        OCR1AH = 0xFF;
    }

    // Clear timeout flag
    TIFR1 |= (1 << OCF1A);

    // Start timer
    TCCR1B |= (1 << CS12)        // Use system clock with /1024 prescaler
           |  (0 << CS11)
           |  (1 << CS10);
}

static void stop_usart_timeout_timer() {
    TCCR1B &= ~((1 << CS12)      // No clock source (timer is stopped)
           |    (1 << CS11)
           |    (1 << CS10));
}

INLINE uint8_t usart_rx_buffer_ready() {
    return (UCSR0A & (1 << RXC0)) > 0;
}

INLINE uint8_t usart_tx_buffer_ready() {
    return (UCSR0A & (1 << UDRE0)) > 0;
}

INLINE uint8_t usart_timed_out() {
    return (TIFR1 & (1 << OCF1A)) > 0;
}

static uint8_t usart_recv_8() {
    while (!usart_rx_buffer_ready() && !usart_timed_out()) {}
    return UDR0;
}

static uint16_t usart_recv_16() {
    const uint8_t h = usart_recv_8();
    return (h << 8) + usart_recv_8();
}

// Reads 256 bytes if bytes == 0
static void usart_recv_block(uint8_t *dst, uint8_t bytes) {
    do {
        while (!usart_rx_buffer_ready() && !usart_timed_out()) {}
        *dst++ = UDR0;
    } while (--bytes && !usart_timed_out());
}

static void usart_send_8(uint8_t data) {
    while (!usart_tx_buffer_ready()) {}
    UDR0 = data;
}

// Uploads 256 bytes if block_size == 0
static void upload_block(const uint8_t *block, uint8_t block_size, uint8_t lock_bus) {
    do {
        // Signal bus release from previous loop
        PORT_SIG1 |= (1 << BUSRQ_SIG1);

        // Wait for an IO request from Z80
        while (PIN_SIG1 & (1 << WAIT_SIG1)) {}

        acquire_data_bus();
        PORT_DATA_BUS = *block++;

        // Signal bus request
        PORT_SIG1 &= ~(1 << BUSRQ_SIG1);
        signal_io_complete();
        // Wait for Z80 to release the bus
        while (PIN_SIG1 & (1 << BUSACK_SIG1)) {}

        release_data_bus();
    } while (--block_size);

    if (!lock_bus) {
        // Signal bus release
        PORT_SIG1 |= (1 << BUSRQ_SIG1);
    }
}

static uint8_t upload_z80_binary_from_usart() {
    uint8_t read_buffer[256];

    setup_usart_timeout_timer();
    
    start_usart_timeout_timer(2);
    uint16_t binary_size = usart_recv_16();
    stop_usart_timeout_timer();
    if (usart_timed_out()) {
        usart_send_8(ERR_TIMEOUT);
        return ERR_TIMEOUT;
    }

    uint8_t block_count = binary_size >> 8;
    if ((binary_size & 0xff) > 0) {
        block_count++;
    }

    // Upload block count
    upload_block(&block_count, 1, 0);
    // Ready for receiving blocks
    usart_send_8(ERR_OK);

    while (binary_size > 0) {
        // chunk_size is one less than actual size
        // to allow 256 byte sized chunks

        start_usart_timeout_timer(1);
        const uint8_t chunk_size = usart_recv_8();
        stop_usart_timeout_timer();
        if (usart_timed_out()) {
            usart_send_8(ERR_TIMEOUT);
            return ERR_TIMEOUT;
        }

        if (chunk_size <= binary_size - 1) {
            usart_send_8(ERR_OK);

        } else {
            // Reject current block (invalid size)
            usart_send_8(ERR_INVALID_SIZE);
            return ERR_INVALID_SIZE;
        }

        // chunk_size is one less than actual size + 1 checksum byte
        start_usart_timeout_timer((uint16_t)chunk_size + 2);
        // chunk_size + 1 may overflow uint8_t but it's handled in usart_recv_block
        usart_recv_block(read_buffer, chunk_size + 1);
        const uint8_t checksum_recv = usart_recv_8();
        stop_usart_timeout_timer();
        if (usart_timed_out()) {
            usart_send_8(ERR_TIMEOUT);
            return ERR_TIMEOUT;
        }

        uint8_t checksum_calc = 0u;
        uint8_t i = chunk_size;
        do {
            checksum_calc ^= read_buffer[i];
        } while (i--);

        if (checksum_recv == checksum_calc) {
            // Keep bus locked after last byte uploaded
            upload_block(read_buffer, 0, binary_size - 1 == chunk_size);
            // Acknowledge current block
            usart_send_8(ERR_OK);

        } else {
            // Reject current block (checksum failed)
            usart_send_8(ERR_CHECKSUM_FAILED);
            return ERR_CHECKSUM_FAILED;
        }

        binary_size -= chunk_size;
        // chunk_size is one less than actual size
        binary_size--;
    }

    return ERR_OK;
}

static void load_z80_binary_from_usart_command() {
    stop_z80_clock();
    disable_z80_cpu();
    cli();
    upload_bootloader();
    enable_z80_cpu();
    start_z80_clock();
    if (upload_z80_binary_from_usart() == ERR_OK) {
        sei();
        bus_release();

    } else {
        stop_z80_clock();
        disable_z80_cpu();
    }
}

int main() {
    cli();
    
    setup_pins();
    setup_usart();
    setup_z80_clock();
    set_memory_bank(2);

    for(;;) {
        const uint8_t command = usart_recv_8();
        switch (command) {
            case CMD_LOAD_Z80_BINARY_FROM_USART:
                load_z80_binary_from_usart_command();
                break;
        }
    }

    return 0;
}

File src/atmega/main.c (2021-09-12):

#define F_CPU 20000000    // AVR clock frequency in Hz, used by util/delay.h


#include <avr/io.h>
#include <util/delay.h>
  
int main() {
    DDRD |= (1<<2);        // set USER LED pin PD2 to output
    while (1) {
        PORTD |= (1<<2);   // drive USER LED pin PD2 high
        _delay_ms(500);    // delay 100 ms
        PORTD &= ~(1<<2);  // drive USER LED pin PD2 low
        _delay_ms(500);    // delay 900 ms
    }
}

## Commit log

2021-09-01 initial HW schema; update readme
    [atmega-z80.kicad_pcb, atmega-z80.sch]
2021-09-02 fix banking logic
    [atmega-z80.sch]
2021-09-05 schema v0.1 - using multiplexers plus some fixes
    [atmega-z80.sch]
2021-09-05 schema v0.2 - reduce the number of resistors
    [atmega-z80.sch]
2021-09-06 minor changes in schema and readme, nothing functional
    [atmega-z80.sch]
2021-09-07 added PCB footprints, changed ISP connector
    [atmega-z80.kicad_pcb, atmega-z80.sch]
2021-09-07 update LED resistors
    [atmega-z80.kicad_pcb, atmega-z80.sch]
2021-09-10 hello world: blinking user led using 20MHz clock
2021-09-12 adding I2C connector and other fixes
    [atmega-z80.sch]
2021-09-13 improving USB IO LED
    [atmega-z80.sch]
2021-09-14 Preliminary PCB layout
    [atmega-z80.kicad_pcb, atmega-z80.sch]
2021-09-18 set USB hardware ID; autodetect the board; update readme
2021-09-19 Reversed all diodes on line USB_IO_LED because GP0 and GP1 of U8 are active low. (#4)
    More PCB layout stuff.
    [atmega-z80.kicad_pcb, atmega-z80.sch]
2021-09-19 update schema version/date/licenses, generate pdf
    [atmega-z80.sch]
2021-09-27 A bunch of improvements / additions (#5)
    * A bunch of improvements / additions
    - PCB layout improvements
    - 1N5817 diode datasheet
    - CMake support
    - ATMega program loader firmware
    - program loader tool (z80_prog_loader.py)
    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
    [atmega-z80.kicad_pcb, atmega-z80.sch]
2021-10-03 PCB routing and Pasmo switch (#6)
    * z80_prog_loader console output and memory banking support
    memory banking logic bugfix
    z80 hello world sample
    * Changed #Z80_RESET line pull-down (R13) to pull-up
    * Switched to Pasmo assembler
    * Added console output handling to z80_prog_loader.py
    * PCB routing complete
    Minor improvements
    [atmega-z80.kicad_pcb, atmega-z80.sch]
2021-10-16 Improvements and bugfixes (#7)
    Small improvements and bugfixes
    - USART timeout checks during Z80 code upload
    - error codes are now returned during Z80 code upload instead of a single ACK/NACK
    - added own implementation of mcp2221 python library due to a bug in the official one
    - updated atmega-z80.pdf
    - minor PCB improvements
    - other small bugfixes in z80_prog_loader.py and blinky.asm
    [atmega-z80.kicad_pcb, atmega-z80.sch]

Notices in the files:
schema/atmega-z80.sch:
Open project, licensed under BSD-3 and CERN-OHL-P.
